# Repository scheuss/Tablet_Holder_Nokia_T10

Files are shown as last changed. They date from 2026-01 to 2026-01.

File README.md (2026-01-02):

# Tablet Holder Nokia T10

## Description
<p>
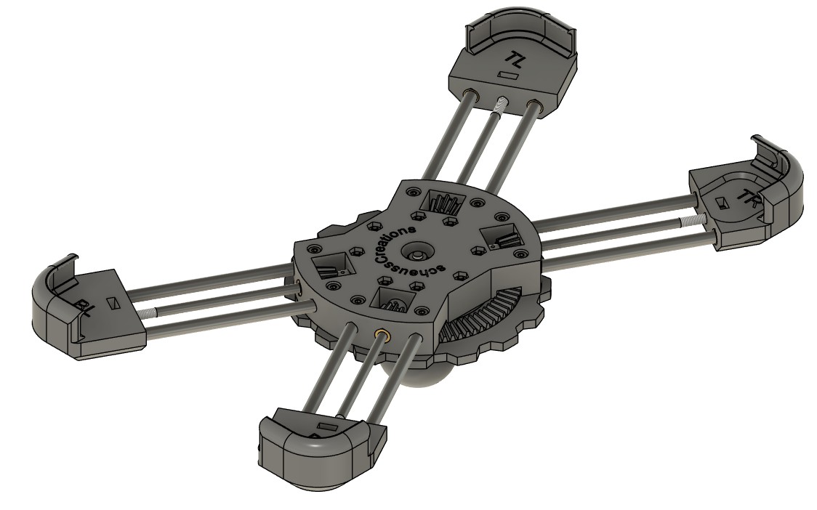
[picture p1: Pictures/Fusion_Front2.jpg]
  
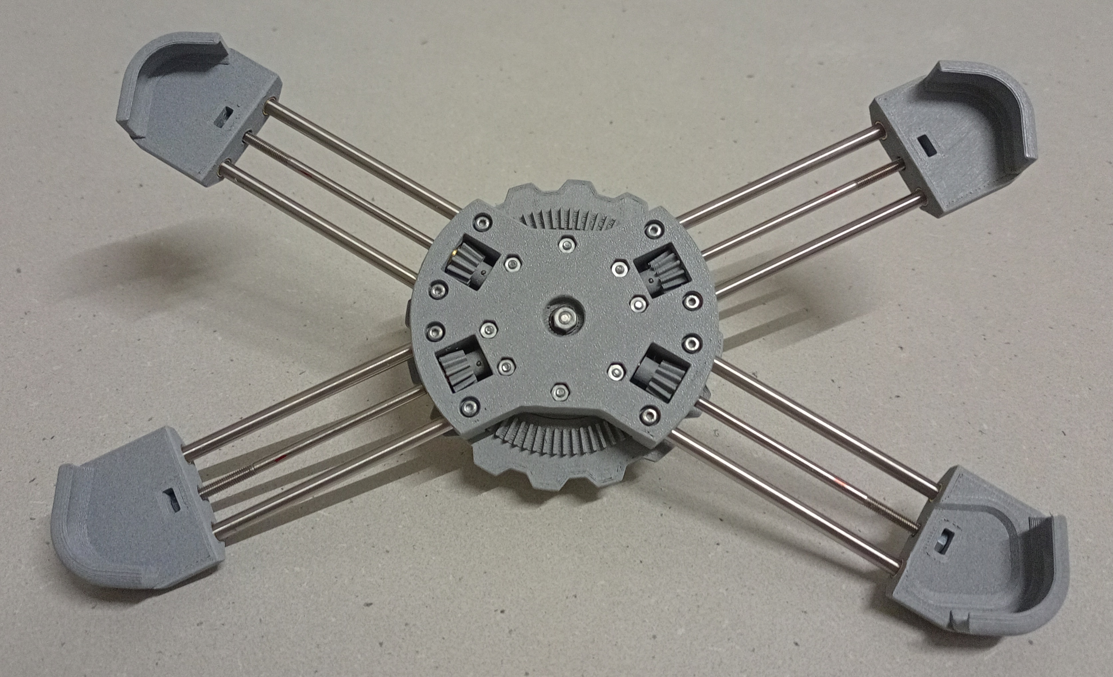
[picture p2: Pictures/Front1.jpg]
  
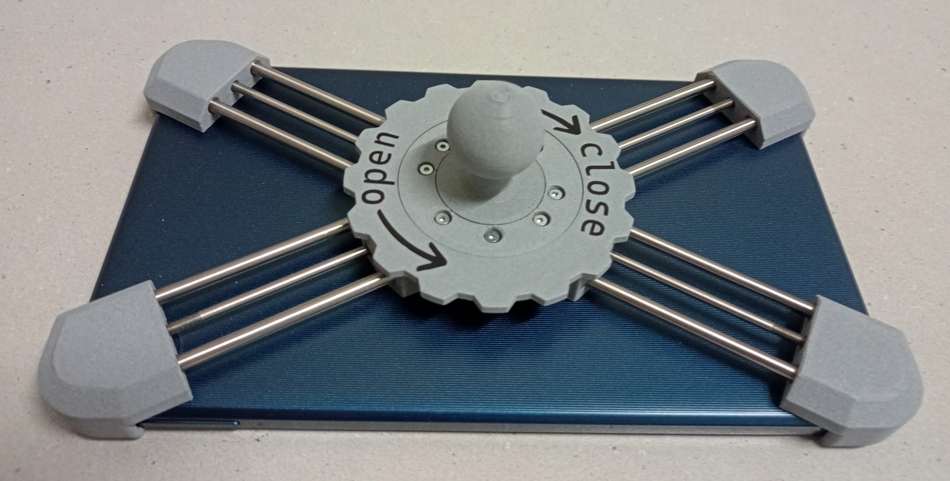
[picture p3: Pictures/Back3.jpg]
  
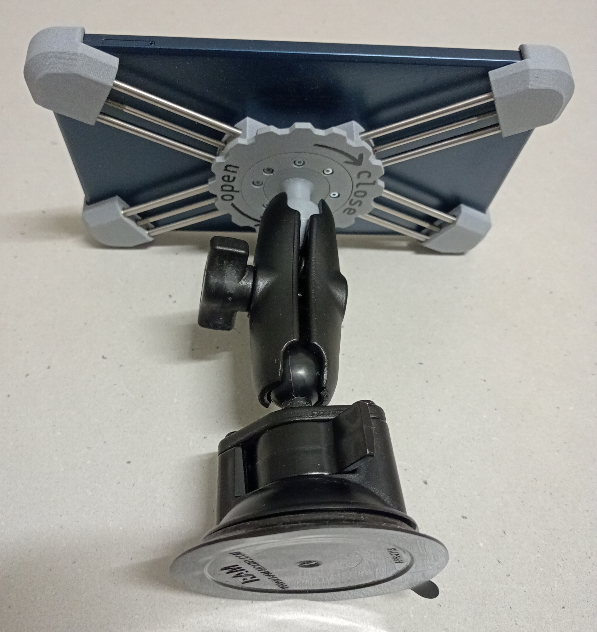
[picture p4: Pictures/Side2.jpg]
  
</p>

This construction is a holder for the Nokia T10 tablet. I couldn’t find a good tablet holder for my Nokia T10, so I designed one myself. By rotating the ring gear on the back side, all four pinion gears drive the M3 spindles. This moves all four corners toward the center and clamps the tablet on all edges. It works very well and the tablet looks good in the holder.

On the back side, there is a spherical mount for attaching a suction mount.

The M3×40 mm threaded rod in the middle is used for stability and prevents the sphere from breaking off. The M3 nut inside the sphere needs to be placed during printing. Simply add a stop at a height of 38.6 mm.

The holder was designed using Fusion 360. The gear is designed with the Fusion app GF Gear Generator.

All 3D-printed parts were printed on a Prusa MK3S+ with a layer height of 0.2 mm. Only the five gear parts were printed with a layer height of 0.1 mm.

It can be easily adapted for other tablets such as iPads or Samsung tablets.

Let me know if you have any questions.

Feel free to build your own tablet holder. Contributions to this project are very welcome; you may use the PayPal link.

## Parts and Materials
- All printed parts are made using ‘ProtoPasta Light Gray Carbon Fiber Composite HTPLA’ filament:
https://proto-pasta.com/products/light-grey-carbon-fiber-composite-htpla?variant=13870367899693  

- The shoulder bushings are sourced from AliExpress (select the correct size) but could also be made from brass:
https://de.aliexpress.com/item/1005009829181558.html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 

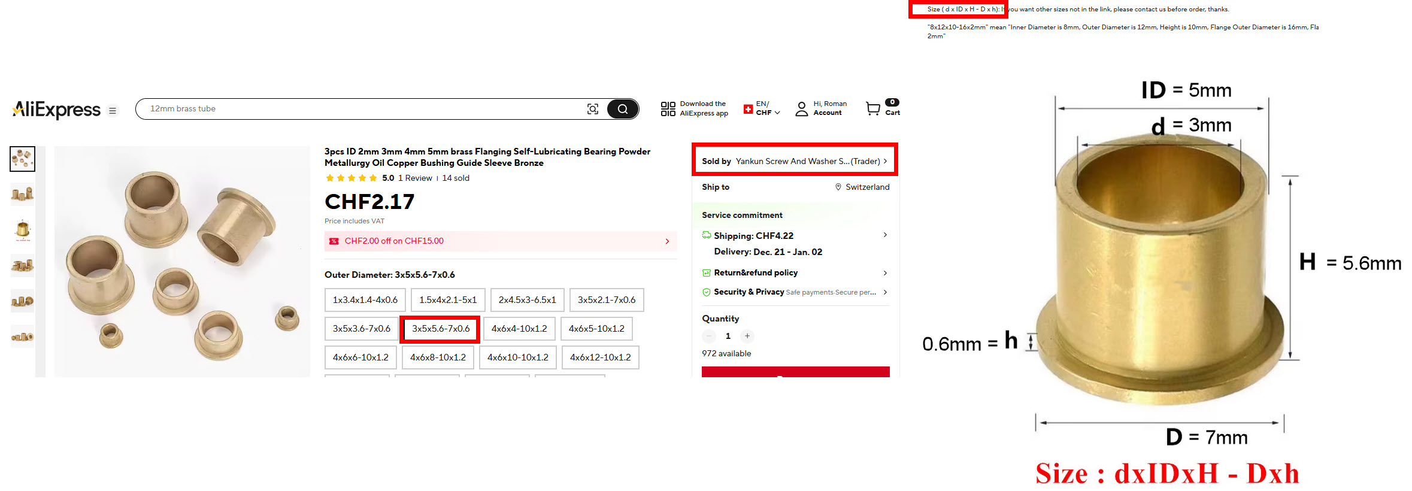
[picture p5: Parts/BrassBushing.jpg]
  

- The other bushings are made from brass tubes with the appropriate diameter.

- The M3 spindles and the other rods are made of stainless steel with a good surface finish (ground and polished?)

- I use the RAM Mount RAM-B-166-103U suction mount:
https://www.rammounts.de/en/part/ram-b-166-103u

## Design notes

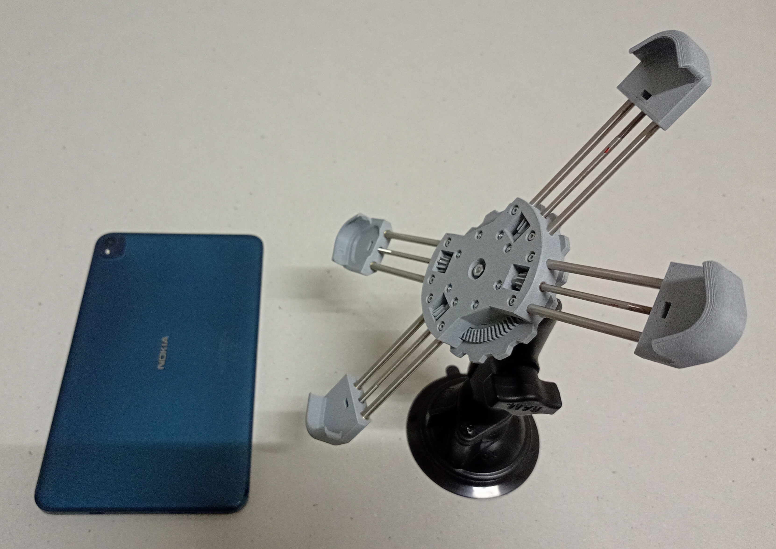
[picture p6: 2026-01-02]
Pictures/Side1.jpg

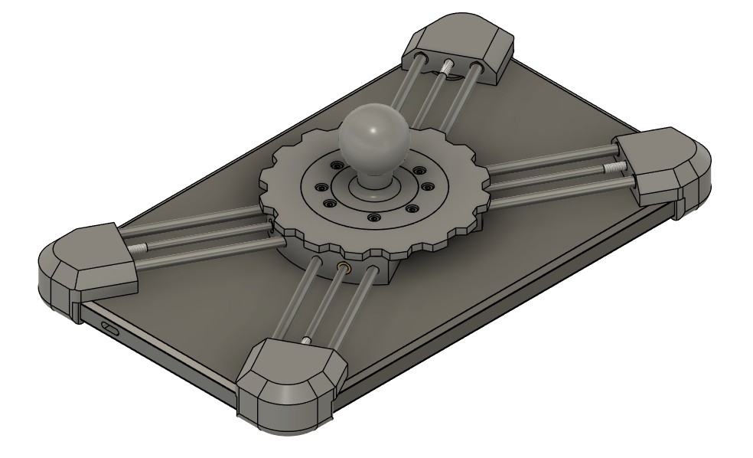
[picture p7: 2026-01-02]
Pictures/Fusion_Back.jpg

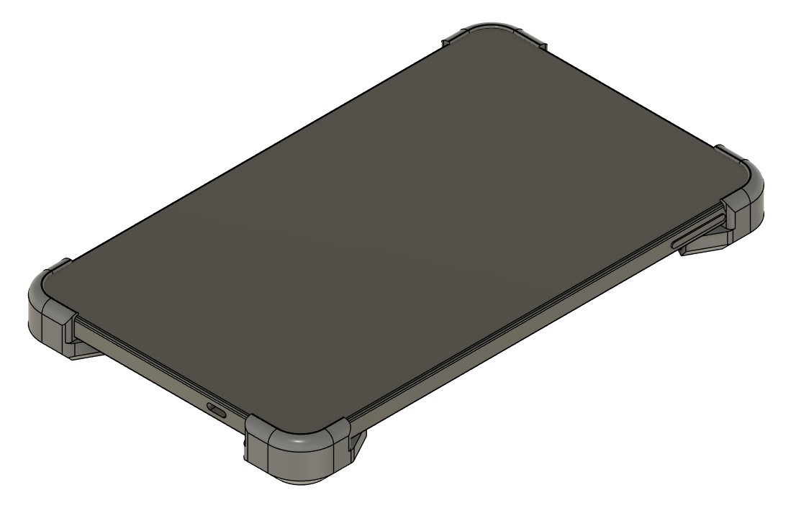
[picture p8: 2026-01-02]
Pictures/Fusion_Front1.jpg

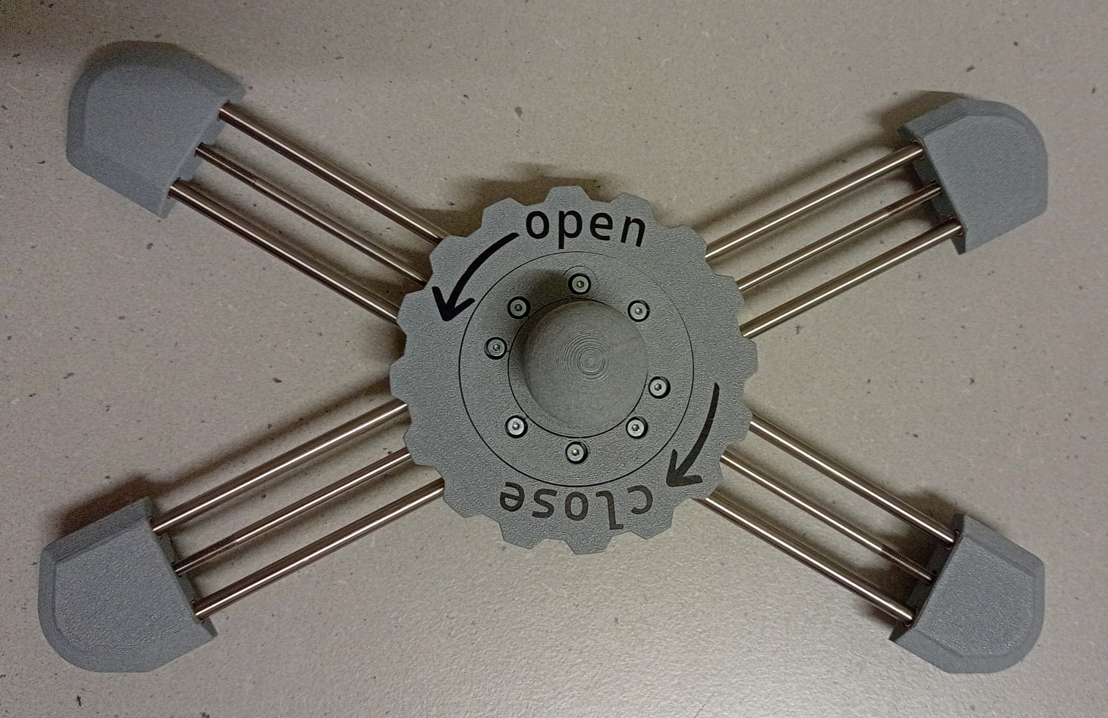
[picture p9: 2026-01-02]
Pictures/Back1.jpg

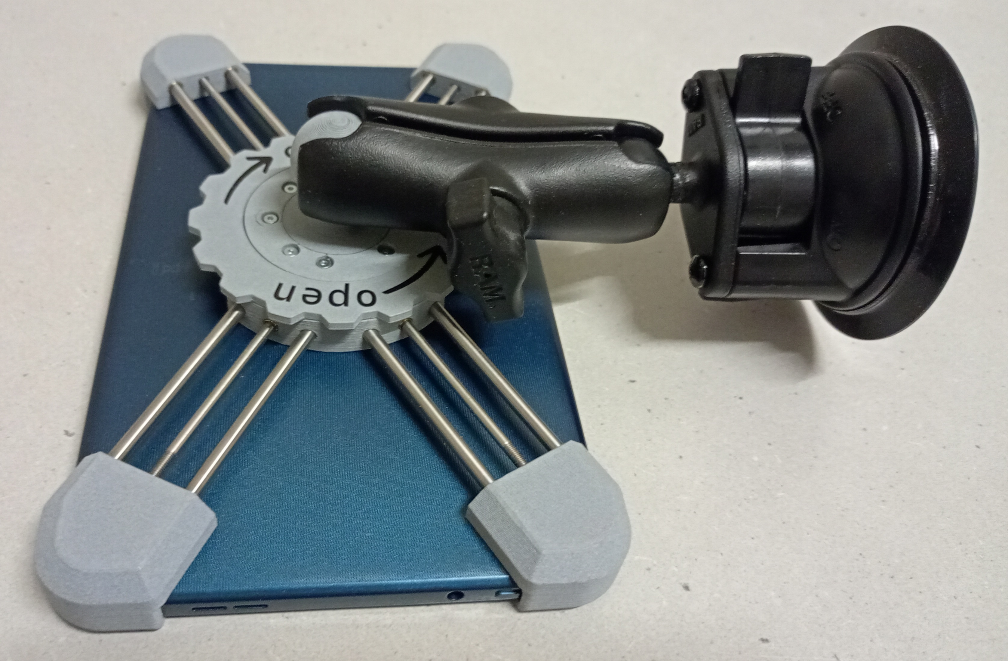
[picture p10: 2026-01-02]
Pictures/Back2.jpg

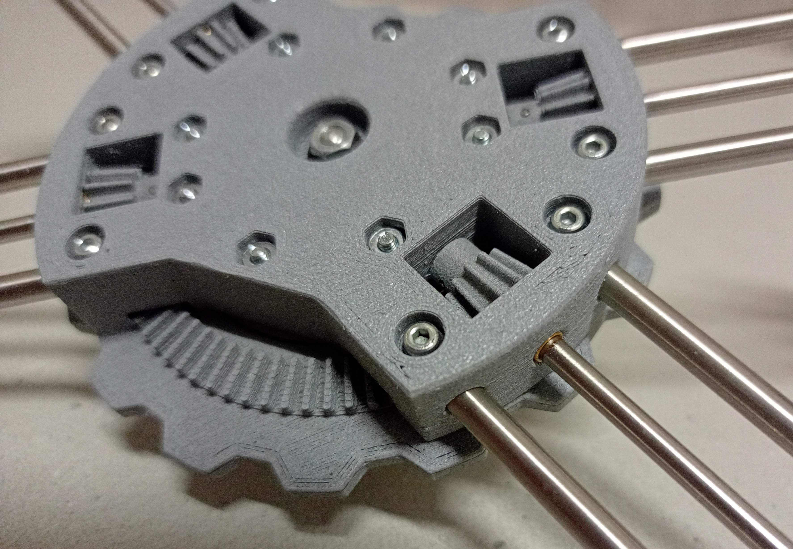
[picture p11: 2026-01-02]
Pictures/Front2.jpg

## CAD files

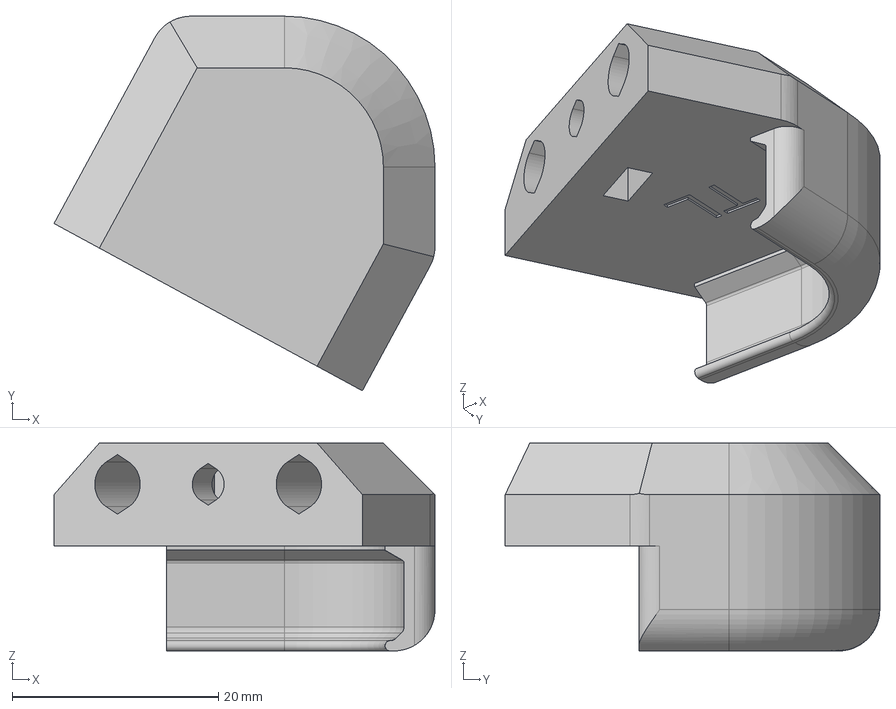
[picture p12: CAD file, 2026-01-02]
Parts/CornerTL.step
36.9 x 36.3 x 20.1 mm

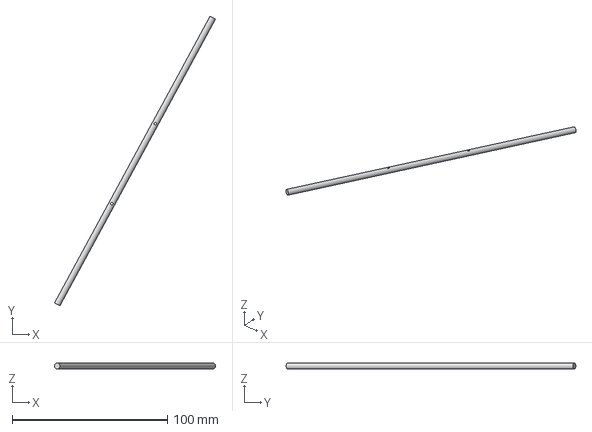
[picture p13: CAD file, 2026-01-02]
Parts/Rod_210mm.step
103.7 x 186.5 x 4.00 mm

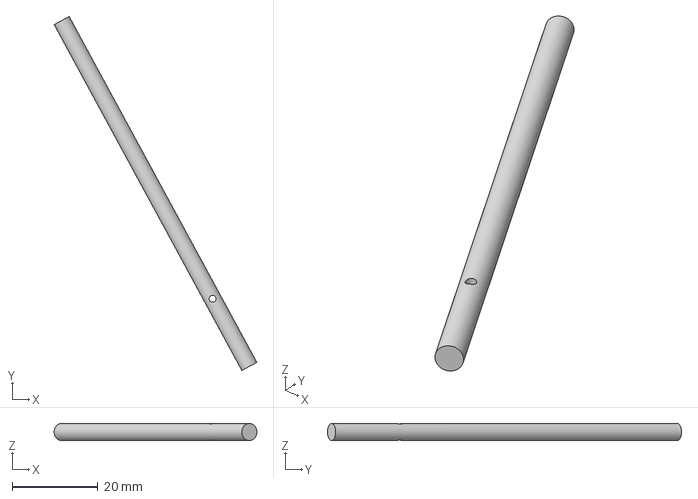
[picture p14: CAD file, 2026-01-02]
Parts/Rod_92mm.step
47.4 x 82.8 x 4.00 mm

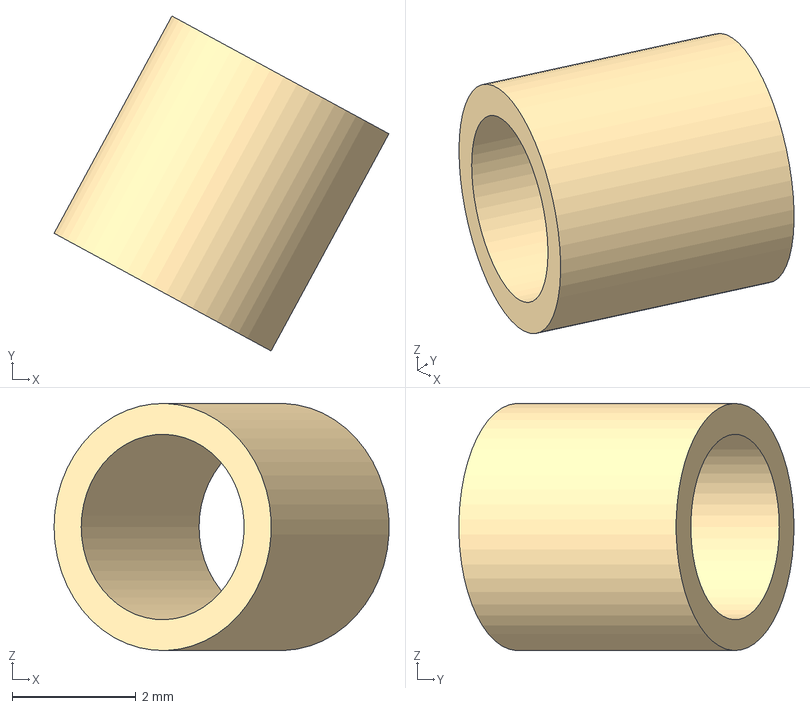
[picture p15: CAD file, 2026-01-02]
Parts/Bushing_4x4mm.step
5.42 x 5.42 x 4.00 mm

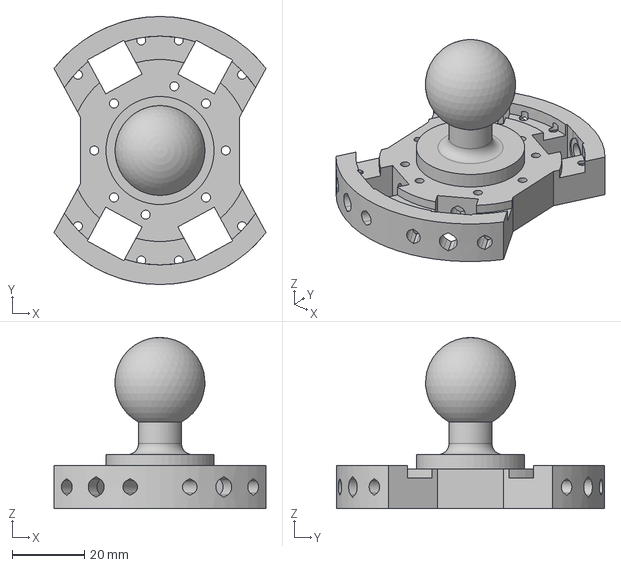
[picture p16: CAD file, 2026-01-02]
Parts/Center.step
58.8 x 74.4 x 47.5 mm

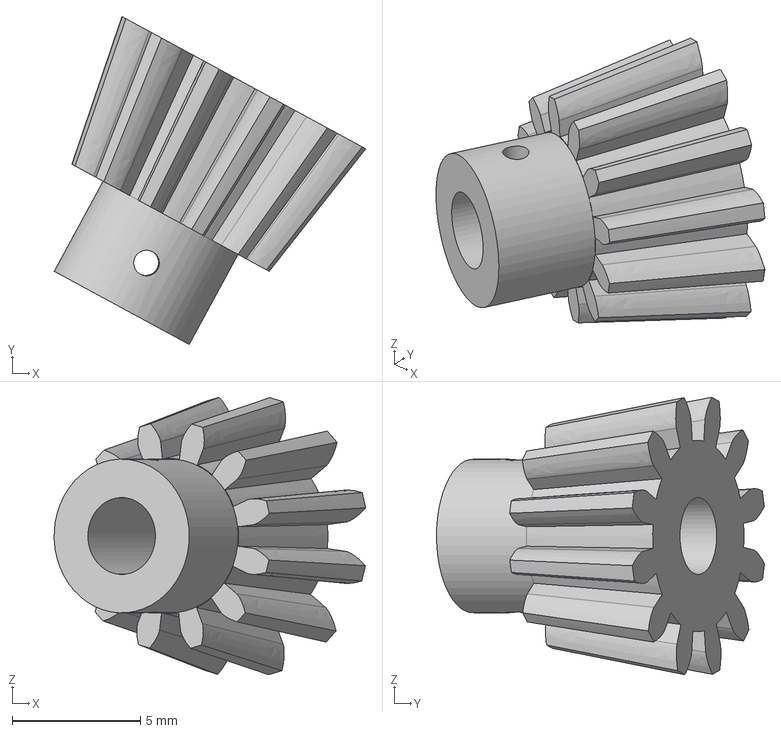
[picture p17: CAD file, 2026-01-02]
Parts/PinionGear.step
12.2 x 12.8 x 10.8 mm

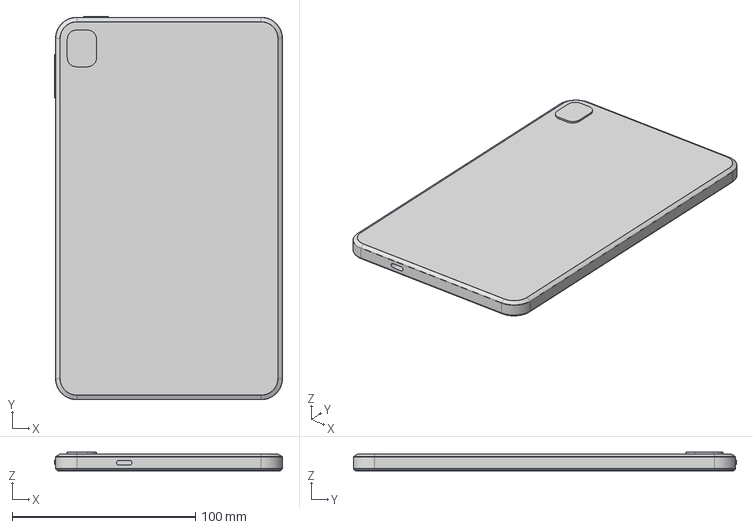
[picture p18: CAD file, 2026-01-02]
Parts/Nokia_T10.step
124.4 x 209.2 x 10.2 mm

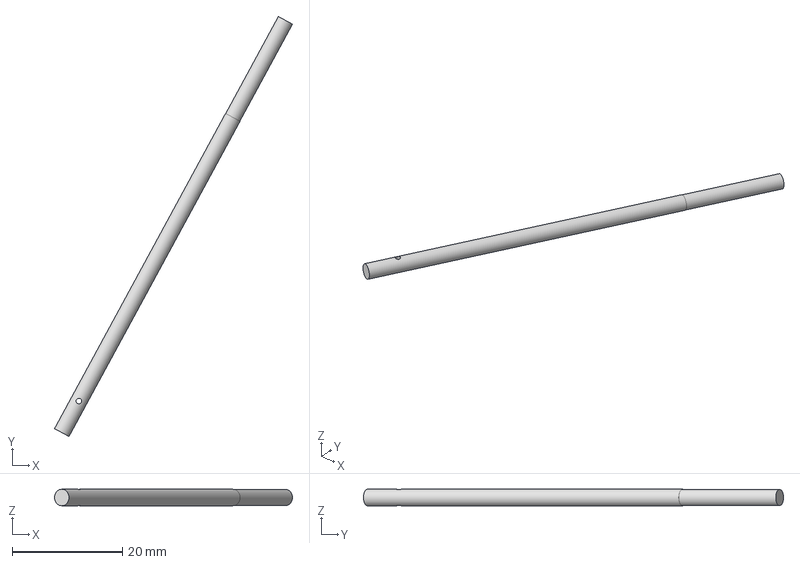
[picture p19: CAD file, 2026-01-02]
Parts/Spindel_M3.step
43.1 x 76.1 x 3.00 mm

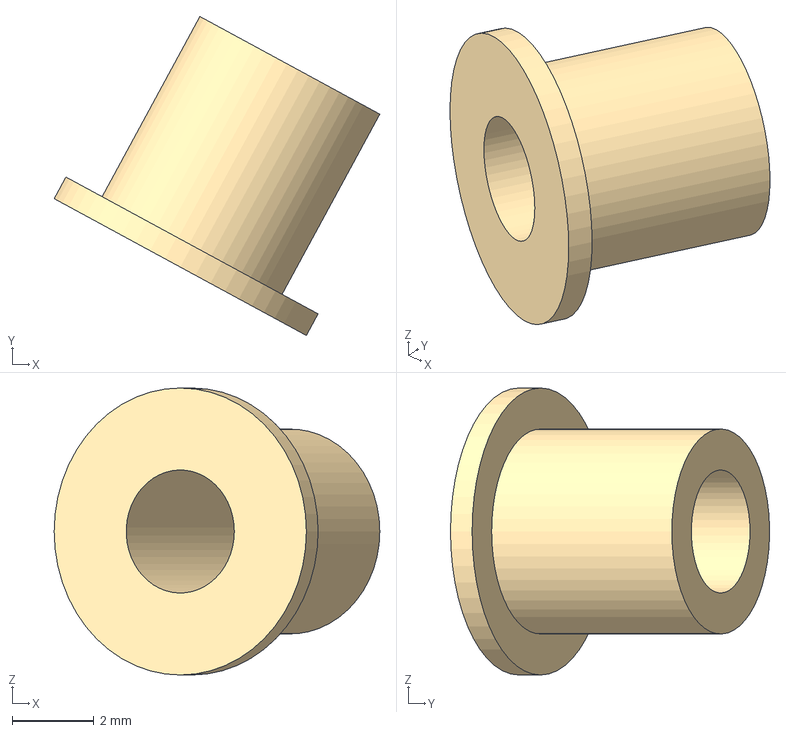
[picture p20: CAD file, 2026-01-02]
Parts/ShoulderBushing.step
7.94 x 7.78 x 7.00 mm

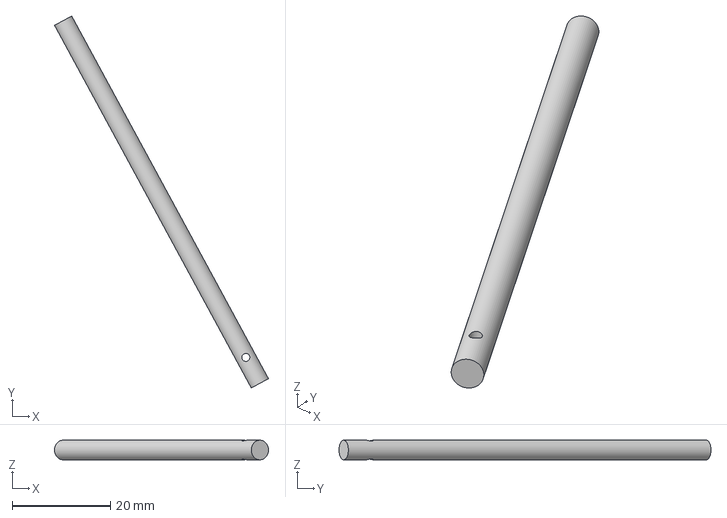
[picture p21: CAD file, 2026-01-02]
Parts/Rod_84mm.step
43.6 x 75.7 x 4.00 mm

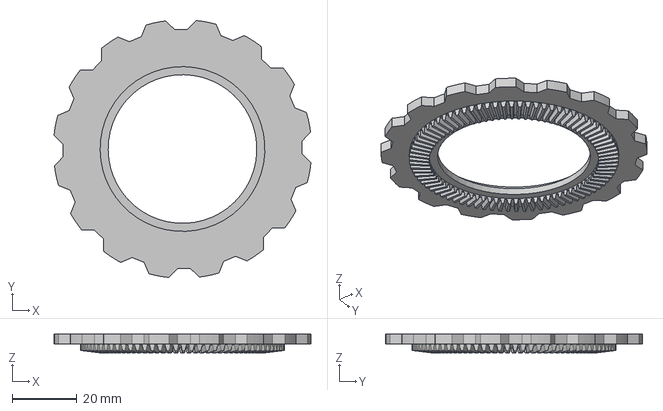
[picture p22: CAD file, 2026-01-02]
Parts/RingGear.step
79.5 x 79.5 x 5.82 mm

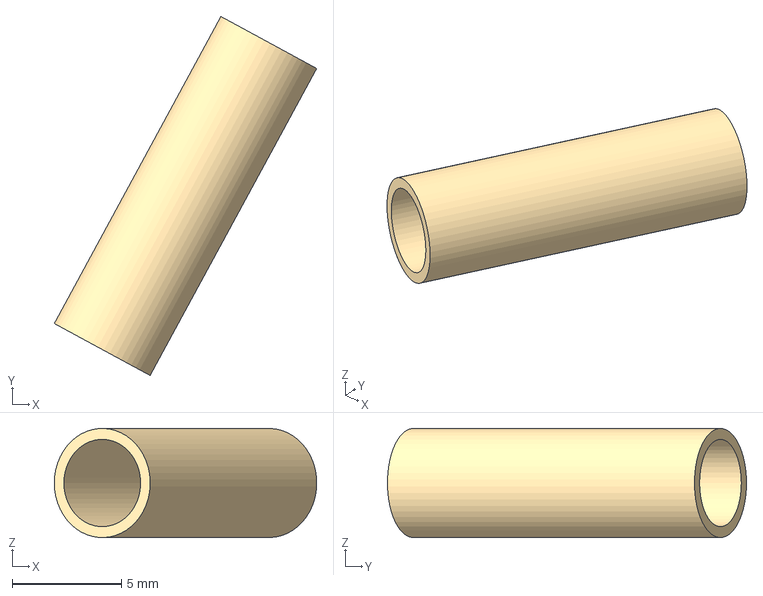
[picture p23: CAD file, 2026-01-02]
Parts/Bushing_5x16mm.step
12.0 x 16.4 x 5.00 mm

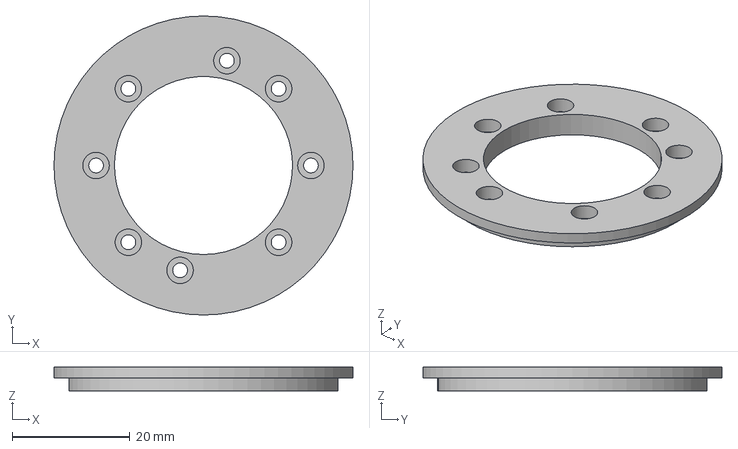
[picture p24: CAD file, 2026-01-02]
Parts/Cover.step
50.8 x 50.8 x 4.00 mm

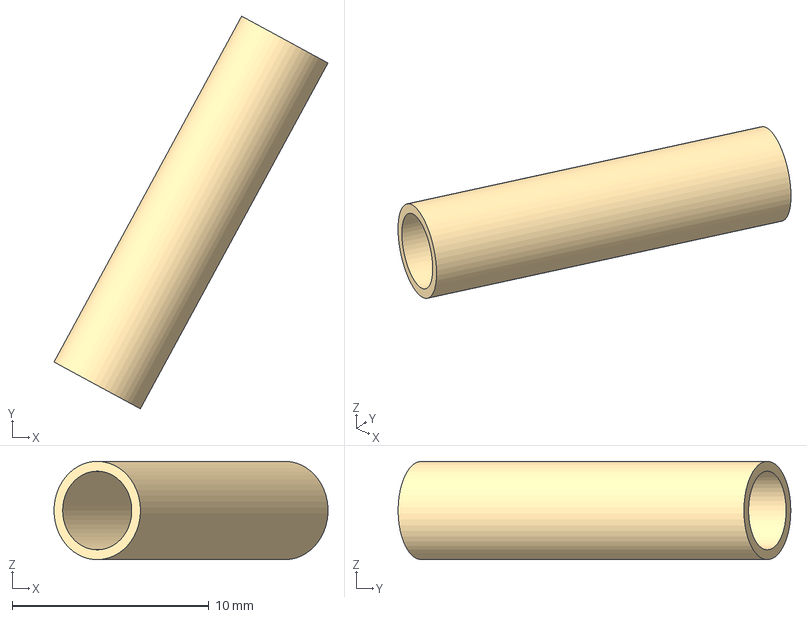
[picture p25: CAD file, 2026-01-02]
Parts/Bushing_5x20mm.step
13.9 x 20.0 x 5.00 mm

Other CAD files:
Parts/Corner_BL.step
Parts/Corner_TR.step
Parts/Corner_BR.step

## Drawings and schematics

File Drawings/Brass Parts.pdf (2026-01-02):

5

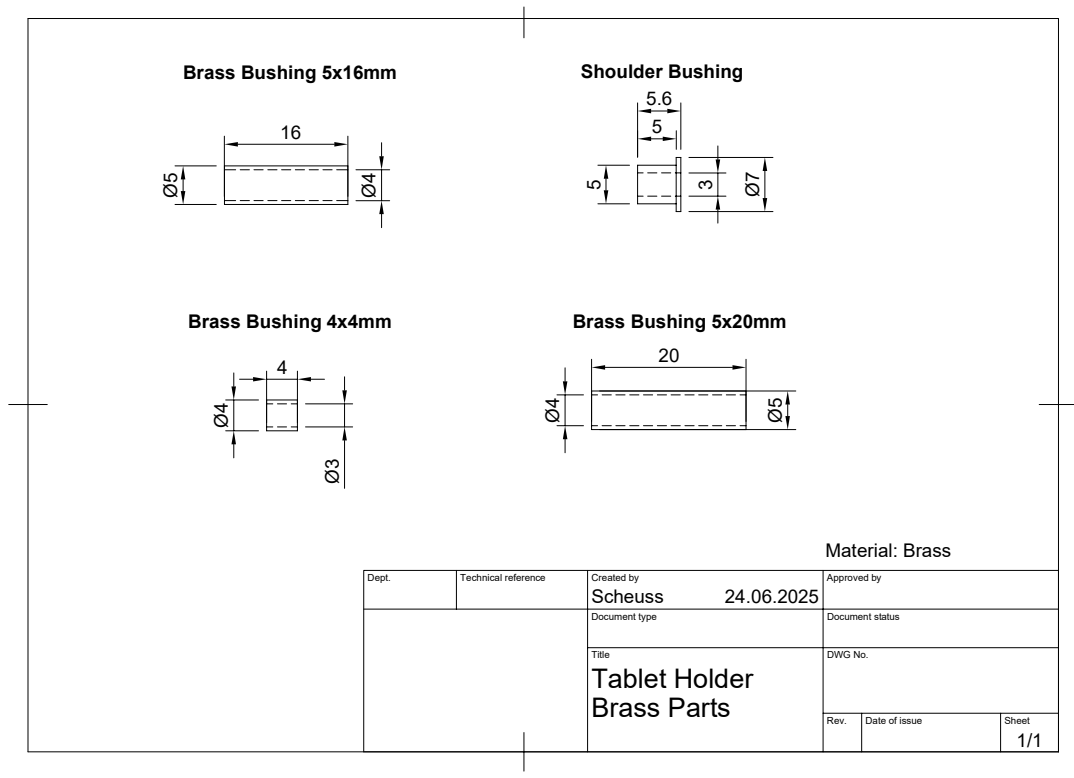
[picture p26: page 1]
Dept.; Technical reference; Created by; Approved by Document type; Document status Title; DWG No. Rev.; Date of issue; Sheet 24.06.2025; 1/1 Brass Parts Tablet Holder Scheuss

Ø3 Brass Bushing 5x16mm Brass Bushing 4x4mm Shoulder Bushing Brass Bushing 5x20mm Material: Brass

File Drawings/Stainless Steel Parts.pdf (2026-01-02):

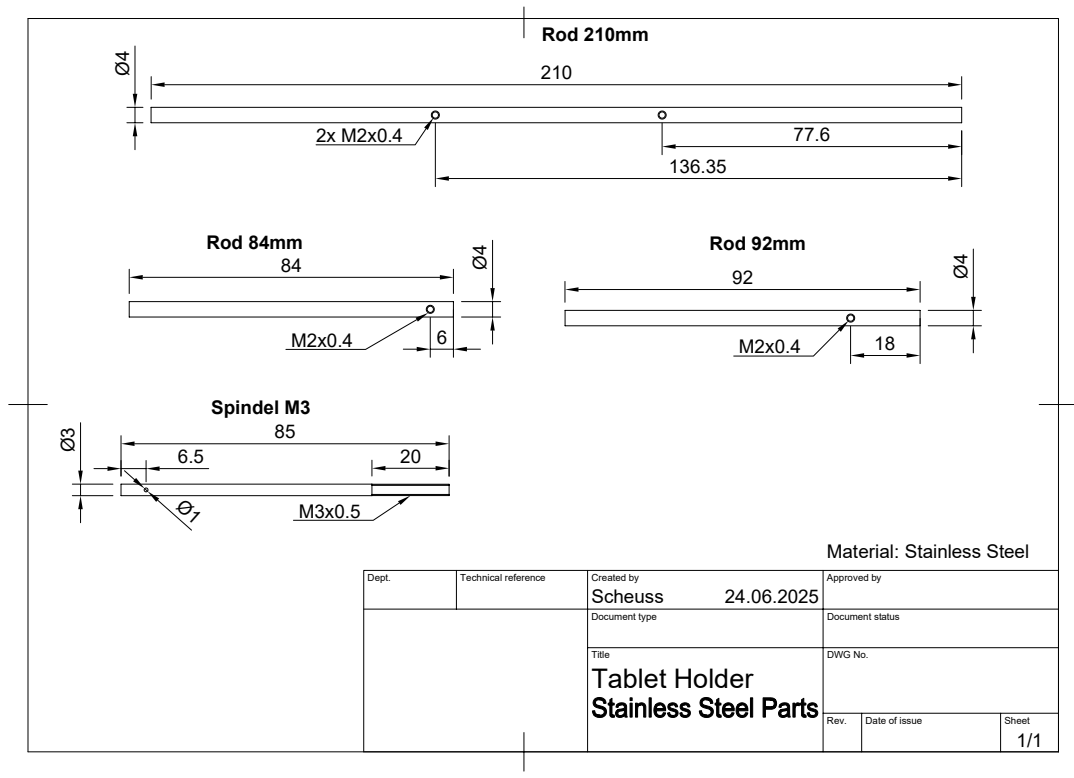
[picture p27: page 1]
Dept.; Technical reference; Created by; Approved by Document type; Document status Title; DWG No. Rev.; Date of issue; Sheet 24.06.2025; 1/1 Tablet Holder Scheuss

Ø3 Material: Stainless Steel Rod 210mm Spindel M3 Rod 84mm Rod 92mm 20 85 M3x0.5

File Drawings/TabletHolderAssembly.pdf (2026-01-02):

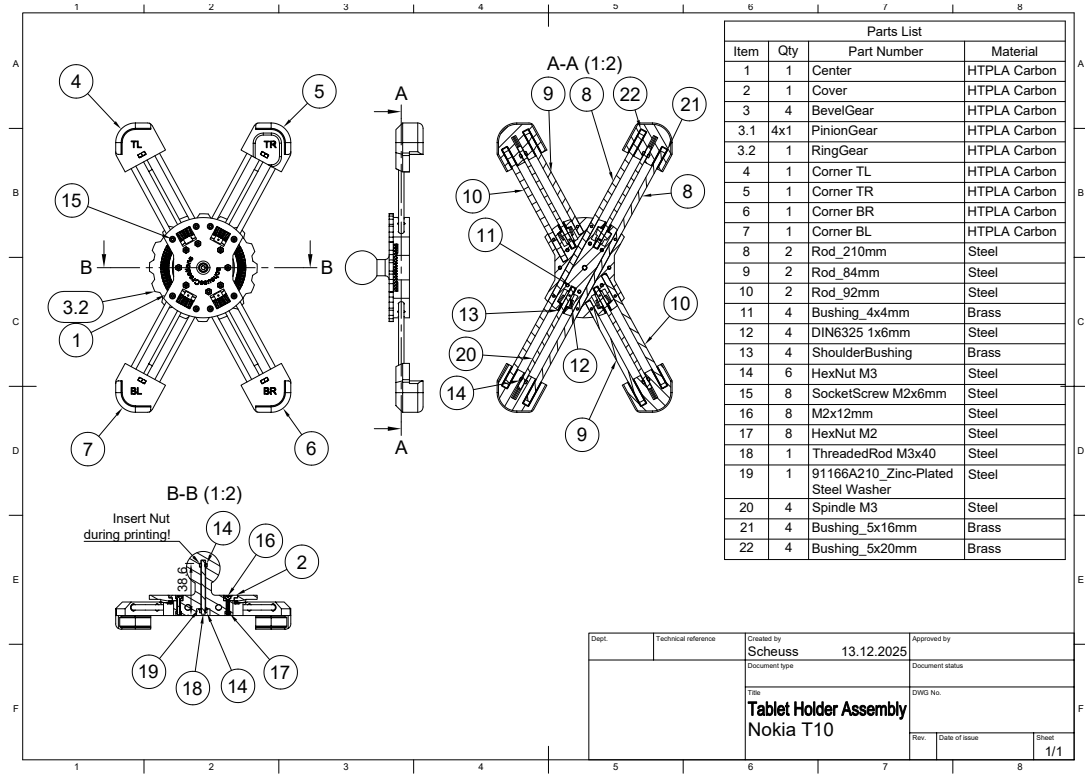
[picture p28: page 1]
8 BCDEF; ABCDEF Dept.; Technical reference; Created by; Approved by Document type; Document status Title; DWG No. Rev.; Date of issue; Sheet 13.12.2025; 1/1 Nokia T10 Scheuss AA; A-A (1:2) Insert Nut during printing!; Parts List Item; Qty; Part Number; Material 1; Center; HTPLA Carbon 2; Cover; HTPLA Carbon 3; BevelGear; HTPLA Carbon 3.1; PinionGear; HTPLA Carbon 3.2; RingGear; HTPLA Carbon 4; Corner TL; HTPLA Carbon 5; Corner TR; HTPLA Carbon 6; Corner BR; HTPLA Carbon 7; Corner BL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

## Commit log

2026-01-02 Design files added
    [Bushing_4x4mm.step, Bushing_5x16mm.step, Bushing_5x20mm.step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]
2026-01-02 Add Baass bushing detail information
2026-01-02 Add print settings
